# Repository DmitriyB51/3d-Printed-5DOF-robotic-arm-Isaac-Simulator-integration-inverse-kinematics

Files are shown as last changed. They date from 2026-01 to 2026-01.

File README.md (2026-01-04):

# 3d Printed 5DOF robotic arm + Isaac-Simulator integration + inverse kinematics
A 3D-printed 5-DOF robotic manipulator designed, built, and simulated from scratch. The project combines mechanical design, inverse kinematics, and digital-twin simulation using NVIDIA Isaac Sim.

<p align="center">
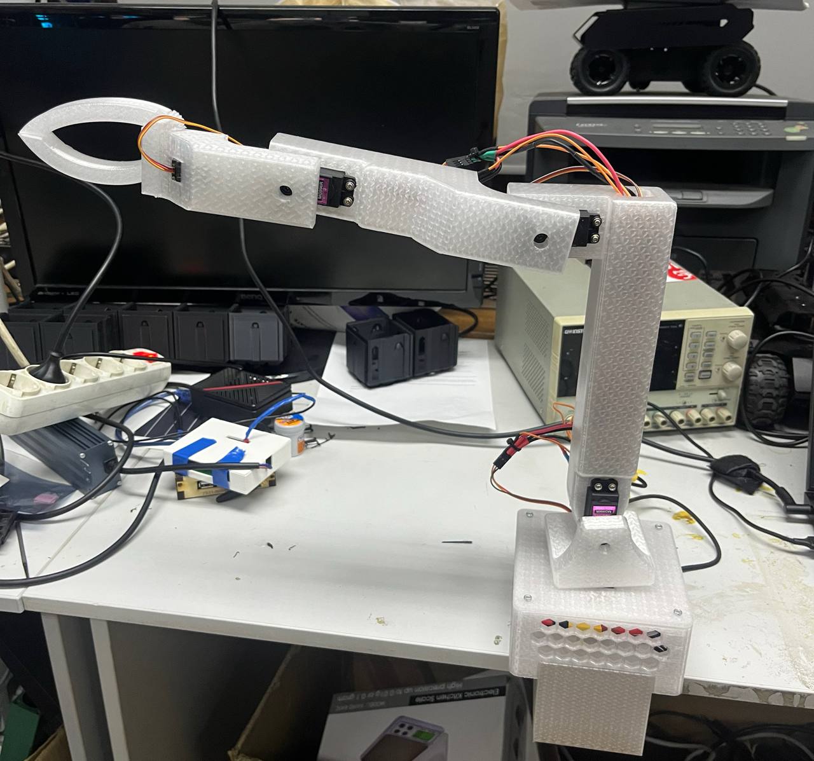
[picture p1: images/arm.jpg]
  
</p>

## Key Features

1) Fully 3D printed

2) Designed in Fusion 360

3) Inverse Kinematics implementation (Python ikpy library, ROS2)

4) URDF model for simulation

5) Integrated with Isaac Sim for realistic physics and motion testing

6) Digital twin: same kinematics for simulation and real hardware

## Quick Links
- [Fusion360](0-docs/1-Fusion360.md)
- [Isaac-Simulator](0-docs/2-Isaac-Simulator.md)
- [Digital-Twin](0-docs/3-digital_twin.md)
- [Inverse-Kinematics](0-docs/4-Inverse-kinematics.md)
- [Key Features](#key-features)
- [Demo](#demo)

## Demo
- Isaac Sim + Inverse Kinematics 

<p align="center">
  
</p>

- Digital twin  

<p align="center">
  
</p>  

## Technical Stack
- Python
- NVIDIA Isaac Sim
- URDF
- IKPy
- Fusion 360
- ESP32, MG996R

## Project Structure
```text
├── 0-docs/      # Documentation
├── urdf/        # Robot description files
├── src/         # Inverse kinematics & control scripts
├── images/      # Images for README
├── media/       # GIFs
└── README.md
```

## Inverse Kinematics
The robotic arm uses inverse kinematics to compute joint angles from a target end-effector position.
The IK solution is implemented in Python using the IKPy library and validated in NVIDIA Isaac Sim.

## Simulation & Digital Twin
The robot is simulated in NVIDIA Isaac Sim using a URDF model.
The same kinematic model is used for both simulation and real hardware, enabling a digital twin workflow.

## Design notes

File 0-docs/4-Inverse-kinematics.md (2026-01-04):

# Inverse Kinematics

## Overview
Inverse kinematics is solved in Python using **IKPy** based on the robot **URDF**.  
The IK output (joint angles) is published to **ROS2** as `sensor_msgs/JointState` and used as a command for Isaac Sim.

**Implementation:** [IK_ROS.py](../src/my_servo_pkg/my_servo_pkg/IK_ROS.py) - ROS2 node for inverse kinematics computation and joint command publishing.

<p align="center">
  
</p> 

---

## Inputs / Outputs
**Input:** target end-effector position `(X, Y, Z)` from terminal  
**Output:** joint angles for 4 revolute joints published to `/joint_command`

---

## IK Model
- IK chain loaded from URDF using `ikpy.chain.Chain.from_urdf_file(...)`
- Active joints are selected via `active_links_mask`
- Joint names used in ROS2 message:
  - `Revolute_1`, `Revolute_6`, `Revolute_2`, `Revolute_4`

---

## Solver Logic
1. Read `(X, Y, Z)`
2. Try multiple candidate orientations (fallback list)
3. Run IKPy `inverse_kinematics()` with `orientation_mode="Y"`
4. Validate solution using forward kinematics:
   - compute end-effector position from `forward_kinematics()`
   - compare with target using a position tolerance

If a valid solution is found, publish the joint angles.

---

## Reachability Check
A solution is accepted only if the computed EE position is within:
- `POSITION_TOLERANCE = 0.04` (meters)

If no orientation reaches the target within tolerance:
- the target is treated as **not reachable**

---

## ROS2 Command Publishing
- Publisher topic: `/joint_command`
- Message type: `sensor_msgs/JointState`
- Publish rate: `30 Hz`
- Each valid solution is published for ~0.5 seconds to ensure Isaac Sim receives it

---

## Notes
- Only joint indices `ik[1:5]` are used (4 joints sent to simulation)
- Angles are published in **radians** (ROS standard)
- Terminal printing converts angles to degrees for readability

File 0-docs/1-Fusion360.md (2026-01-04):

# Fusion 360 Modeling

## Overview
The 5-DOF robotic arm was fully designed and assembled in **Autodesk Fusion 360** to validate geometry, joint layout, and manufacturability before simulation and hardware implementation.

**Fusion 360 CAD Model:** [Download robo-arm.f3d](../STEP/robo-arm.f3d) - Complete 3D assembly file with all components and joints.

**URDF Robot Description:** [View URDF](../urdf/urdf/Untitled.urdf) - Robot description file exported from Fusion 360 for simulation.

<p align="center">
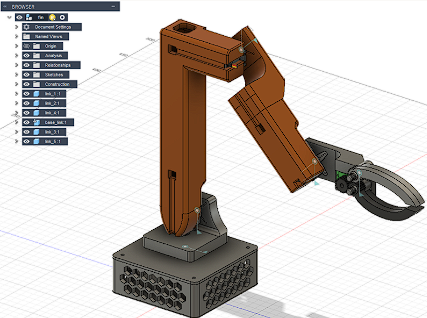
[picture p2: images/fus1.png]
  
</p>
*Figure 1: Complete robotic arm assembly in Fusion 360*

<p align="center">
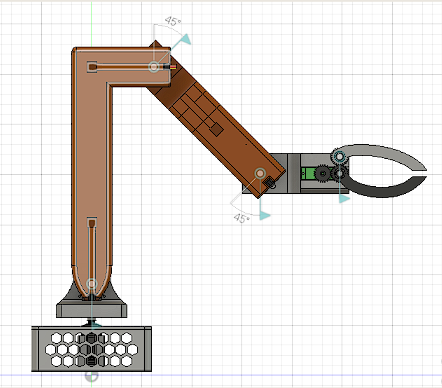
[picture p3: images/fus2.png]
  
</p>
*Figure 2: Joint configuration and kinematic chain*

<p align="center">
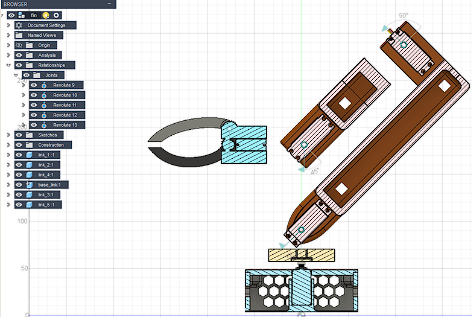
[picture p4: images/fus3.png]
  
</p>
*Figure 3: Individual link components and servo mounting*

---

## Design Characteristics
- 5-DOF servo-driven mechanical structure  
- Designed around **MG996R servo motors**  
- Compact link geometry to reduce torque load  
- Modular parts for easy replacement  
- Suitable for URDF export and simulation  

---

## Mechanical Structure
The arm consists of:
- Base rotation
- Shoulder
- Elbow
- Wrist
- Servo-driven gripper

Each link is modeled as a separate component and connected using rotational joints that match real servo axes.

---

## Assembly and Joints
- Components assembled using Fusion 360 joint constraints  
- Joint limits aligned with servo motion range  
- Assembly hierarchy matches the kinematic chain  

This allows direct mapping between CAD, URDF, IK model, and simulation.

---

## Geometry Optimization
- Reduced lever arms where possible  
- Weight reduction via internal cutouts  
- Reinforced joint regions for load handling  

---

## 3D Printing
- Designed for FDM 3D printing  
- Clearances for screws and servo mounts  
- Modular printable components  

---

## Project Role
The Fusion 360 model is the mechanical reference for:
- URDF robot description  
- Inverse kinematics implementation  
- NVIDIA Isaac Sim digital twin  

---

## Future Improvements
- Weight reduction  
- Gripper refinement  
- Cable routing

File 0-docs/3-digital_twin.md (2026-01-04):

# Digital Twin

## Overview
The project uses a **digital twin workflow**: joint motion is validated in simulation (Isaac Sim) and then sent to real hardware using the same joint naming and control pipeline.

---

<p align="center">
  
</p>

## Data Flow (Simulation → Hardware)
1. **Isaac Sim** publishes simulated joint angles to `/joint_states` (`sensor_msgs/JointState`)
2. ROS2 node converts joint angles (rad → deg) and applies servo calibration offsets
3. Converted angles are published to `/servo_angles` (`std_msgs/Float32MultiArray`)
4. **ESP32 (micro-ROS)** subscribes to `servo_angles` and drives 5 servos using PWM microseconds

**ROS2 Conversion Node:** [joint_reader.py](../src/my_servo_pkg/my_servo_pkg/joint_reader.py) - Converts joint states from simulation to servo angles for hardware.
---

## ROS2 Conversion Node (JointToTwoServos)
- Subscribes: `/joint_states`
- Publishes: `/servo_angles`
- Target joints:
  - `Revolute_1`, `Revolute_6`, `Revolute_2`, `Revolute_4`, `Revolute_5`
- Converts radians to degrees and applies per-joint offsets to match real servo zero positions:
  - `Revolute_1`, `Revolute_6`: `(deg - 90) * (-1)`
  - `Revolute_2`, `Revolute_4`: `deg + 90`

---
**ESP32 Firmware:** [usb_final.ino](../../arduino_ide_src/usb_final/usb_final.ino) - micro-ROS node that receives servo angles and controls 5 MG996R servos via PWM.

## micro-ROS ESP32 Servo Node
- Transport: **serial** (`MICRO_ROS_TRANSPORT_SERIAL`)
- Subscribes: `servo_angles` (`Float32MultiArray`)
- Expects 5 angles (degrees)
- Clamps each angle to `[0, 180]`
- Maps degrees to PWM pulse width:
  - `SERVO_MIN_US = 500`
  - `SERVO_MAX_US = 2500`
- Outputs PWM via `ESP32Servo` on pins:
  - S1=13, S2=14, S3=15, S4=12, S5=19

---

## Purpose
- Use simulation as a safe test environment
- Keep joint naming consistent between simulation and hardware
- Convert simulation joint angles into real servo commands
- Run the same motion pipeline for both digital and physical robot

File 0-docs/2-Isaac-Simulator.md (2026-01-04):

# Isaac Sim Integration

## Overview
The robot is simulated in **NVIDIA Isaac Sim** using a URDF model generated from the Fusion 360 design.

<p align="center">
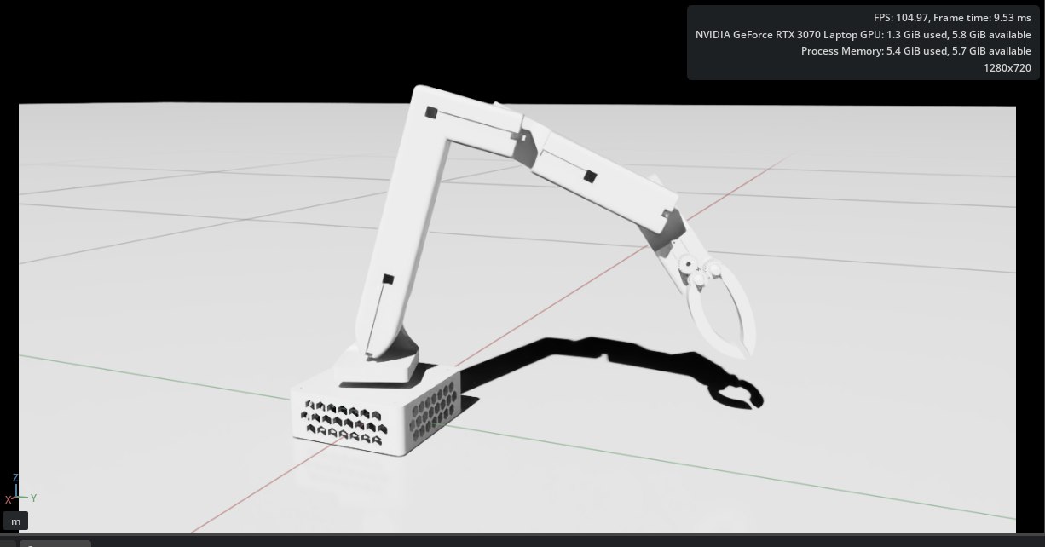
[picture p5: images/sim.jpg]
  
</p> 

---

## URDF
- Matches mechanical structure
- Correct joint axes and limits
- Used as the simulation base model

---

## Control
- Isaac Sim **Action Graph**
- ROS2 communication

<p align="center">
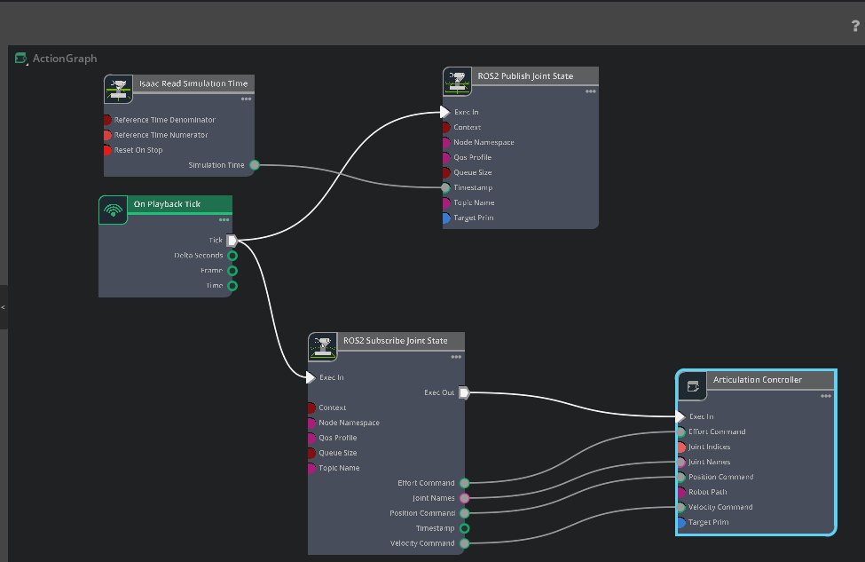
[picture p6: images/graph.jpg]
  
</p>

**Data flow:**
1. Target joint values received from ROS2 / micro-ROS
2. Joint positions applied in simulation
3. Current joint states published to `/joint_states`

## Purpose
- Validate inverse kinematics
- Test motion before hardware
- Digital twin verification

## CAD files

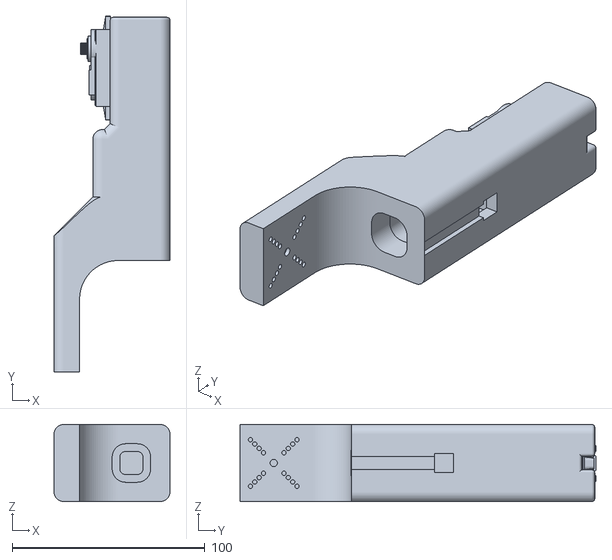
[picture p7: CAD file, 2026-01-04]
urdf/meshes/link_3_1.stl
60.2 x 184.7 x 40.0

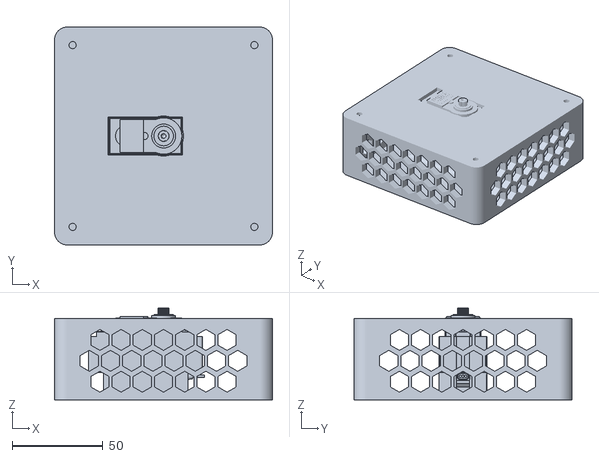
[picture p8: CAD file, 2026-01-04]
urdf/meshes/base_link.stl
120.0 x 120.0 x 50.5

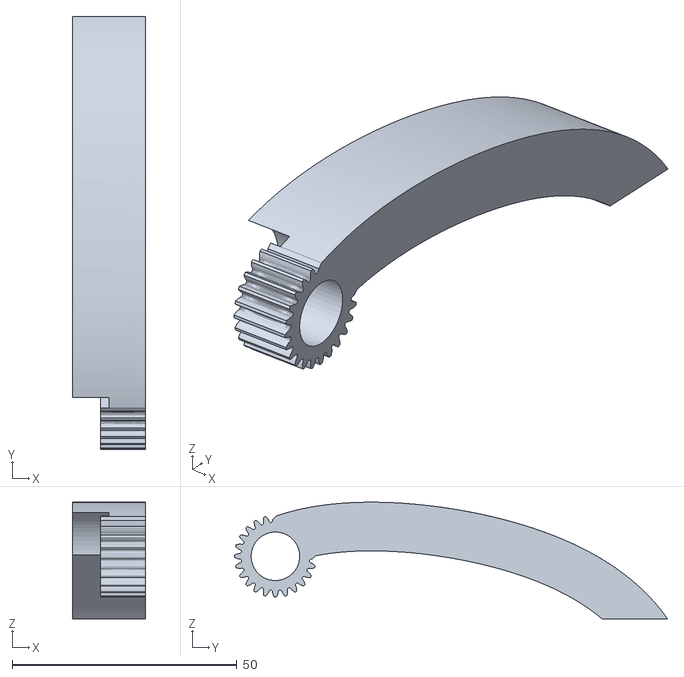
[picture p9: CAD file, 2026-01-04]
urdf/meshes/link_5__1.stl
16.2 x 96.3 x 25.9

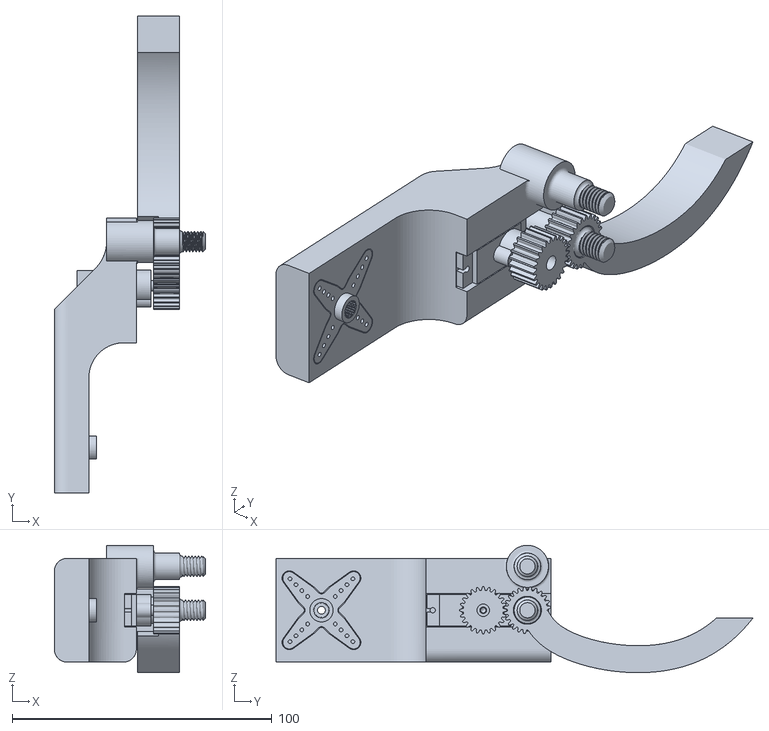
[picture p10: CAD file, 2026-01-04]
urdf/meshes/link_4_1.stl
58.3 x 183.6 x 49.0

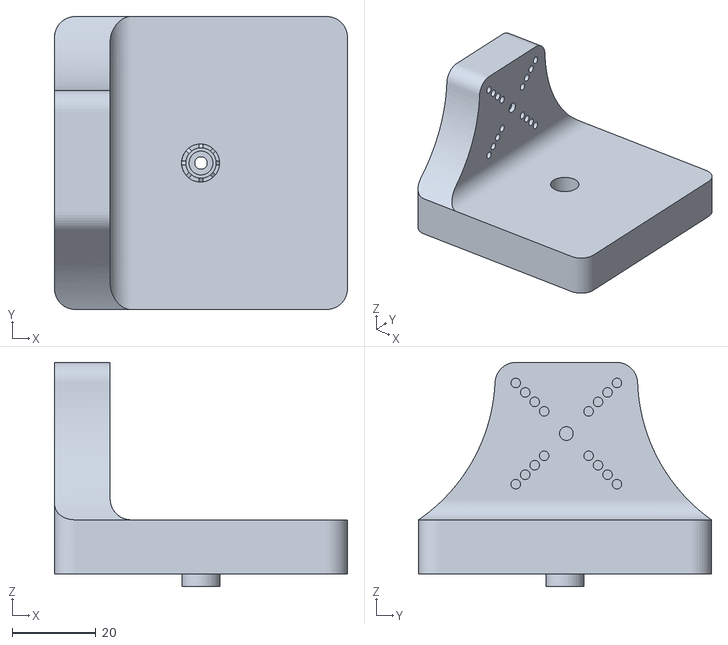
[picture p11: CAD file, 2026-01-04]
urdf/meshes/link_1__1.stl
70.0 x 70.0 x 53.6

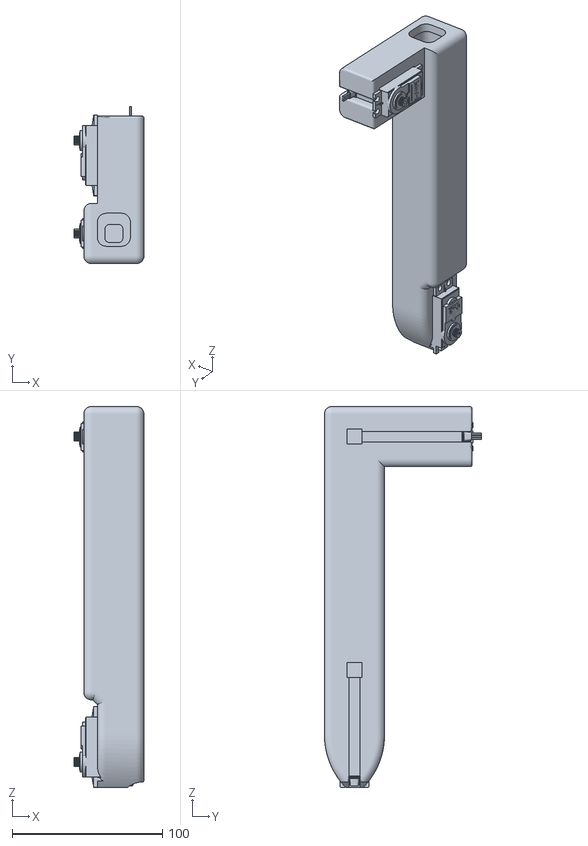
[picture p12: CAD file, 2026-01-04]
urdf/meshes/link_2_1.stl
46.5 x 104.5 x 253.3

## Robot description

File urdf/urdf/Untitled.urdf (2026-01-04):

<?xml version="1.0" ?>
<robot name="Untitled" xmlns:xacro="http://www.ros.org/wiki/xacro">

<xacro:include filename="$(find Untitled_description)/urdf/materials.xacro" />
<xacro:include filename="$(find Untitled_description)/urdf/Untitled.trans" />
<xacro:include filename="$(find Untitled_description)/urdf/Untitled.gazebo" />
<link name="base_link">
  <inertial>
    <origin xyz="-0.0027038397852555225 -5.423781482548487e-07 0.03174826003804549" rpy="0 0 0"/>
    <mass value="1.5829941031835308"/>
    <inertia ixx="0.002267" iyy="0.002381" izz="0.003913" ixy="0.0" iyz="-0.0" ixz="-3.2e-05"/>
  </inertial>
  <visual>
    <origin xyz="0 0 0" rpy="0 0 0"/>
    <geometry>
      <mesh filename="package://Untitled_description/meshes/base_link.stl" scale="0.001 0.001 0.001"/>
    </geometry>
    <material name="silver"/>
  </visual>
  <collision>
    <origin xyz="0 0 0" rpy="0 0 0"/>
    <geometry>
      <mesh filename="package://Untitled_description/meshes/base_link.stl" scale="0.001 0.001 0.001"/>
    </geometry>
  </collision>
</link>

<link name="link_1__1">
  <inertial>
    <origin xyz="-0.007277512033058122 4.8763026692895006e-05 0.011631486838158726" rpy="0 0 0"/>
    <mass value="0.6495824188722104"/>
    <inertia ixx="0.000323" iyy="0.000392" izz="0.000536" ixy="1e-06" iyz="-1e-06" ixz="7.9e-05"/>
  </inertial>
  <visual>
    <origin xyz="-9.9e-05 1e-06 -0.051" rpy="0 0 0"/>
    <geometry>
      <mesh filename="package://Untitled_description/meshes/link_1__1.stl" scale="0.001 0.001 0.001"/>
    </geometry>
    <material name="silver"/>
  </visual>
  <collision>
    <origin xyz="-9.9e-05 1e-06 -0.051" rpy="0 0 0"/>
    <geometry>
      <mesh filename="package://Untitled_description/meshes/link_1__1.stl" scale="0.001 0.001 0.001"/>
    </geometry>
  </collision>
</link>

<link name="link_3_1">
  <inertial>
    <origin xyz="0.0192845282791872 0.08685469809762955 -3.156043858915103e-05" rpy="0 0 0"/>
    <mass value="1.4865137140753586"/>
    <inertia ixx="0.003842" iyy="0.000685" izz="0.004094" ixy="-0.000824" iyz="3e-06" ixz="0.0"/>
  </inertial>
  <visual>
    <origin xyz="0.021561 -0.06222 -0.300343" rpy="0 0 0"/>
    <geometry>
      <mesh filename="package://Untitled_description/meshes/link_3_1.stl" scale="0.001 0.001 0.001"/>
    </geometry>
    <material name="silver"/>
  </visual>
  <collision>
    <origin xyz="0.021561 -0.06222 -0.300343" rpy="0 0 0"/>
    <geometry>
      <mesh filename="package://Untitled_description/meshes/link_3_1.stl" scale="0.001 0.001 0.001"/>
    </geometry>
  </collision>
</link>

<link name="link_4_1">
  <inertial>
    <origin xyz="0.007813210338647607 0.05502777991911034 -0.0014764267544294385" rpy="0 0 0"/>
    <mass value="0.7277784603492614"/>
    <inertia ixx="0.001233" iyy="0.000251" izz="0.001273" ixy="-0.00032" iyz="9.3e-05" ixz="2.3e-05"/>
  </inertial>
  <visual>
    <origin xyz="0.021153 -0.212439 -0.300151" rpy="0 0 0"/>
    <geometry>
      <mesh filename="package://Untitled_description/meshes/link_4_1.stl" scale="0.001 0.001 0.001"/>
    </geometry>
    <material name="silver"/>
  </visual>
  <collision>
    <origin xyz="0.021153 -0.212439 -0.300151" rpy="0 0 0"/>
    <geometry>
      <mesh filename="package://Untitled_description/meshes/link_4_1.stl" scale="0.001 0.001 0.001"/>
    </geometry>
  </collision>
</link>

<link name="link_5__1">
  <inertial>
    <origin xyz="-0.0077871703186344465 0.041438327284405274 0.0013652582724152929" rpy="0 0 0"/>
    <mass value="0.11824706989499154"/>
    <inertia ixx="7.6e-05" iyy="7e-06" izz="7.4e-05" ixy="1e-06" iyz="1.2e-05" ixz="0.0"/>
  </inertial>
  <visual>
    <origin xyz="-0.01425 -0.291717 -0.317051" rpy="0 0 0"/>
    <geometry>
      <mesh filename="package://Untitled_description/meshes/link_5__1.stl" scale="0.001 0.001 0.001"/>
    </geometry>
    <material name="silver"/>
  </visual>
  <collision>
    <origin xyz="-0.01425 -0.291717 -0.317051" rpy="0 0 0"/>
    <geometry>
      <mesh filename="package://Untitled_description/meshes/link_5__1.stl" scale="0.001 0.001 0.001"/>
    </geometry>
  </collision>
</link>

<link name="link_2_1">
  <inertial>
    <origin xyz="0.027286924725137916 0.012329686820526884 0.13082314360398872" rpy="0 0 0"/>
    <mass value="2.3683472111587176"/>
    <inertia ixx="0.017119" iyy="0.01594" izz="0.001914" ixy="-3.2e-05" iyz="-0.002492" ixz="-1e-05"/>
  </inertial>
  <visual>
    <origin xyz="0.021599 -0.000328 -0.083958" rpy="0 0 0"/>
    <geometry>
      <mesh filename="package://Untitled_description/meshes/link_2_1.stl" scale="0.001 0.001 0.001"/>
    </geometry>
    <material name="silver"/>
  </visual>
  <collision>
    <origin xyz="0.021599 -0.000328 -0.083958" rpy="0 0 0"/>
    <geometry>
      <mesh filename="package://Untitled_description/meshes/link_2_1.stl" scale="0.001 0.001 0.001"/>
    </geometry>
  </collision>
</link>

<joint name="Revolute 1" type="revolute">
  <origin xyz="9.9e-05 -1e-06 0.051" rpy="0 0 0"/>
  <parent link="base_link"/>
  <child link="link_1__1"/>
  <axis xyz="-0.0 0.0 -1.0"/>
  <limit upper="1.570796" lower="-1.570796" effort="100" velocity="100"/>
</joint>

<joint name="Revolute 2" type="revolute">
  <origin xyz="3.8e-05 0.061892 0.216385" rpy="0 0 0"/>
  <parent link="link_2_1"/>
  <child link="link_3_1"/>
  <axis xyz="-1.0 0.0 0.0"/>
  <limit upper="1.570796" lower="-1.570796" effort="100" velocity="100"/>
</joint>

<joint name="Revolute 4" type="revolute">
  <origin xyz="0.000408 0.150219 -0.000192" rpy="0 0 0"/>
  <parent link="link_3_1"/>
  <child link="link_4_1"/>
  <axis xyz="-1.0 -0.0 0.0"/>
  <limit upper="1.570796" lower="-1.570796" effort="100" velocity="100"/>
</joint>

<joint name="Revolute 5" type="revolute">
  <origin xyz="0.035403 0.079278 0.0169" rpy="0 0 0"/>
  <parent link="link_4_1"/>
  <child link="link_5__1"/>
  <axis xyz="1.0 0.0 -0.0"/>
  <limit upper="1.570796" lower="-1.570796" effort="100" velocity="100"/>
</joint>

<joint name="Revolute 6" type="revolute">
  <origin xyz="-0.021698 0.000329 0.032958" rpy="0 0 0"/>
  <parent link="link_1__1"/>
  <child link="link_2_1"/>
  <axis xyz="-1.0 0.0 -0.0"/>
  <limit upper="1.570796" lower="-1.570796" effort="100" velocity="100"/>
</joint>

</robot>

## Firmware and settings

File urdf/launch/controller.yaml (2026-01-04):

Untitled_controller:
  # Publish all joint states -----------------------------------
  joint_state_controller:
    type: joint_state_controller/JointStateController
    publish_rate: 50

  # Position Controllers --------------------------------------
  Revolute 1_position_controller:
    type: effort_controllers/JointPositionController
    joint: Revolute 1
    pid: {p: 100.0, i: 0.01, d: 10.0}
  Revolute 2_position_controller:
    type: effort_controllers/JointPositionController
    joint: Revolute 2
    pid: {p: 100.0, i: 0.01, d: 10.0}
  Revolute 4_position_controller:
    type: effort_controllers/JointPositionController
    joint: Revolute 4
    pid: {p: 100.0, i: 0.01, d: 10.0}
  Revolute 5_position_controller:
    type: effort_controllers/JointPositionController
    joint: Revolute 5
    pid: {p: 100.0, i: 0.01, d: 10.0}
  Revolute 6_position_controller:
    type: effort_controllers/JointPositionController
    joint: Revolute 6
    pid: {p: 100.0, i: 0.01, d: 10.0}

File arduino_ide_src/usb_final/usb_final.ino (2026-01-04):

#include <ESP32Servo.h>
#define MICRO_ROS_TRANSPORT_SERIAL
#include <micro_ros_arduino.h>
#include <rcl/rcl.h>
#include <rclc/rclc.h>
#include <rclc/executor.h>
#include <std_msgs/msg/float32_multi_array.h>


#define SERVO1_PIN    13
#define SERVO2_PIN    14
#define SERVO3_PIN    15
#define SERVO4_PIN    12

#define SERVO5_PIN    19



#define SERVO_MIN_US  500
#define SERVO_MAX_US  2500

Servo servo1;
Servo servo2;
Servo servo3;
Servo servo4;

Servo servo5;


// micro-ROS 
rcl_subscription_t   subscriber;
rclc_executor_t      executor;
rcl_node_t           node;
rclc_support_t       support;
rcl_allocator_t      allocator;
std_msgs__msg__Float32MultiArray servo_msg;


#define RCCHECK(fn) { \
  rcl_ret_t rc = fn; \
  if (rc != RCL_RET_OK) { \
    Serial.print("Error in " #fn ": "); \
    Serial.println(rc); \
    while(1) { delay(100); } \
  } \
}


void servo_callback(const void * msgin)
{
  const std_msgs__msg__Float32MultiArray * msg =
    (const std_msgs__msg__Float32MultiArray *)msgin;

  if (msg->data.size < 5) {
    Serial.println("[WARN] not enough data in servo_angles");
    return;
  }

  float angle1 = msg->data.data[0];
  float angle2 = msg->data.data[1];
  float angle3 = msg->data.data[2];
  float angle4 = msg->data.data[3];

  float angle5 = msg->data.data[4];



  if (angle1 < 0) angle1 = 0;
  if (angle1 > 180) angle1 = 180;

  if (angle2 < 0) angle2 = 0;
  if (angle2 > 180) angle2 = 180;

  if (angle3 < 0) angle3 = 0;
  if (angle3 > 180) angle3 = 180;

  if (angle4 < 0) angle4 = 0;
  if (angle4 > 180) angle4 = 180;

  if (angle5 < 0) angle5 = 0;
  if (angle5 > 180) angle5 = 180;



  int pulse1 = SERVO_MIN_US + (angle1 / 180.0f) * (SERVO_MAX_US - SERVO_MIN_US);
  int pulse2 = SERVO_MIN_US + (angle2 / 180.0f) * (SERVO_MAX_US - SERVO_MIN_US);
  int pulse3 = SERVO_MIN_US + (angle3 / 180.0f) * (SERVO_MAX_US - SERVO_MIN_US);
  int pulse4 = SERVO_MIN_US + (angle4 / 180.0f) * (SERVO_MAX_US - SERVO_MIN_US);

  int pulse5 = SERVO_MIN_US + (angle5 / 180.0f) * (SERVO_MAX_US - SERVO_MIN_US);

  servo1.writeMicroseconds(pulse1);
  servo2.writeMicroseconds(pulse2);
  servo3.writeMicroseconds(pulse3);
  servo4.writeMicroseconds(pulse4);

  servo5.writeMicroseconds(pulse5);

  Serial.printf(
    "[CB] angles: %.2f %.2f %.2f %.2f %.2f | pulses: %d %d %d %d %d\n",
    angle1, angle2, angle3, angle4, angle5,
    pulse1, pulse2, pulse3, pulse4, pulse5
  );
}

//setup 
void setup()
{
  Serial.begin(115200);
  delay(1000);

  
  servo1.attach(SERVO1_PIN, SERVO_MIN_US, SERVO_MAX_US);
  servo2.attach(SERVO2_PIN, SERVO_MIN_US, SERVO_MAX_US);
  servo3.attach(SERVO3_PIN, SERVO_MIN_US, SERVO_MAX_US);
  servo4.attach(SERVO4_PIN, SERVO_MIN_US, SERVO_MAX_US);

  servo5.attach(SERVO5_PIN, SERVO_MIN_US, SERVO_MAX_US);



  // usb
  set_microros_transports(); 


  allocator = rcl_get_default_allocator();
  RCCHECK(rclc_support_init(&support, 0, NULL, &allocator));

  RCCHECK(rclc_node_init_default(
    &node,
    "esp32_servo_node",
    "",
    &support
  ));

  //  memory
  std_msgs__msg__Float32MultiArray__init(&servo_msg);
  servo_msg.data.data = (float*) malloc(5 * sizeof(float));
  servo_msg.data.capacity = 5;
  servo_msg.data.size = 0;

  //creating subscriber
  RCCHECK(rclc_subscription_init_default(
    &subscriber,
    &node,
    ROSIDL_GET_MSG_TYPE_SUPPORT(std_msgs, msg, Float32MultiArray),
    "servo_angles"
  ));

  RCCHECK(rclc_executor_init(&executor, &support.context, 1, &allocator));
  RCCHECK(rclc_executor_add_subscription(
    &executor,
    &subscriber,
    &servo_msg,
    &servo_callback,
    ON_NEW_DATA
  ));

  Serial.println("micro-ROS serial node ready");
}


void loop()
{
  rclc_executor_spin_some(&executor, 0);
}

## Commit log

2026-01-04 Add complete project files: Arduino code, URDF models, inverse kinematics implementation, and documentation
    [Untitled.urdf, base_link.stl, controller.yaml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]
2026-01-04 Rename manipulator_description folder to urdf
    [Untitled.urdf, base_link.stl, controller.yaml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]
